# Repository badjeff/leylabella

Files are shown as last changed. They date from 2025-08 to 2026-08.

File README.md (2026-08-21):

# leylabella



### design principles
- symmetrical computer mouse
- all gripping surface covering with unique curvy descent, generate unique touch memory of gripping, amplify awaring of grip slip to reduce grip adjustment duration
- narrowing frontend bottom, increase pinky side friction, enhance lift and pitch control for flick movement
- 8 customisable buttons
- not-too-bad middle click
- able to trigger side button by squeezing the stams of thumb or ring finger, ensure fingertip does not need to slip around
- no visible screws
- adjustable surface sensor position. with PAW3395 breakout pcb. https://github.com/badjeff/paw3395-pcb
- mini finger trackball. with PMW3610 breakout pcb. https://github.com/badjeff/pmw3610-pcb
- mechnical trackball tightness control
- powered by [ZMK](https://github.com/zmkfirmware/zmk) => OSS, on-devie profiling, say no to (logxtxxh|razxx) eco-system
- magnetic hotswap palm rest (optimized for all grip style)
- medium size (claw grip @ 112mm x 61mm x 38mm; palm grip @ 117mm x 61mm x 38mm)
- rigid. (Zero crackly sound)
- stupidly easy facelifting. (see CAD file, open soruced, playback the timeline)
- ligthweight. (Errr, under 80g, made by PLA body with two sensors)
- fair battery life
- silent tactile switches
- conventional scroll wheel option

### gallery

<p float="left">
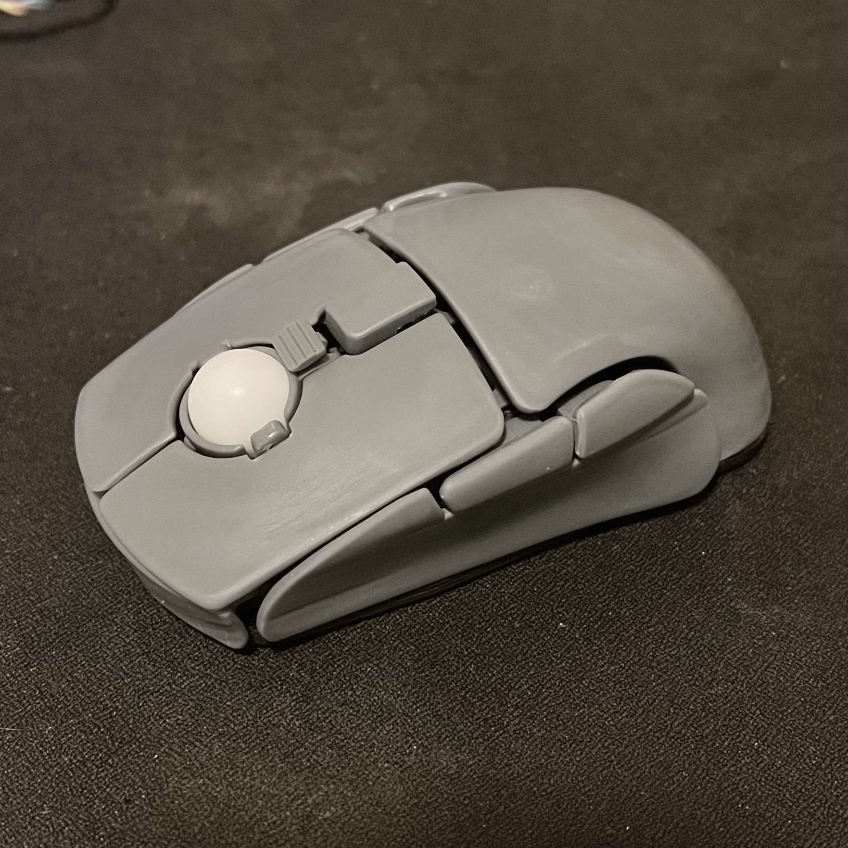
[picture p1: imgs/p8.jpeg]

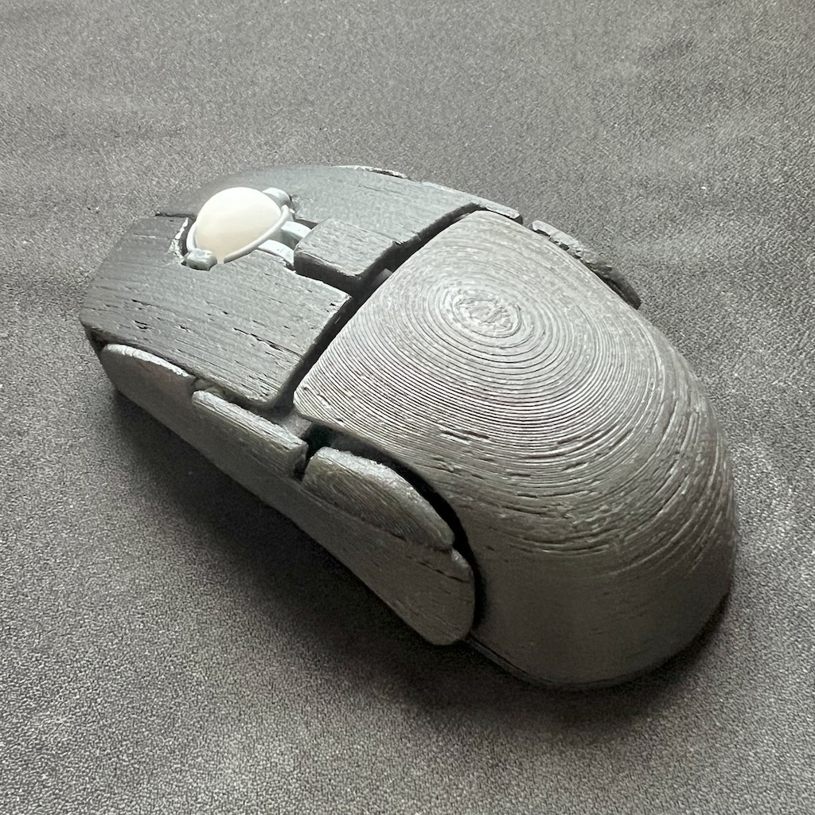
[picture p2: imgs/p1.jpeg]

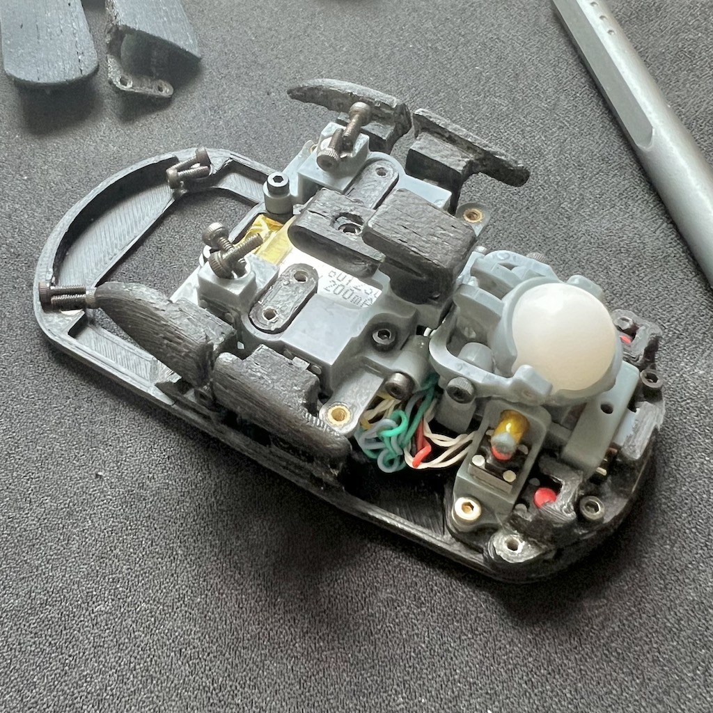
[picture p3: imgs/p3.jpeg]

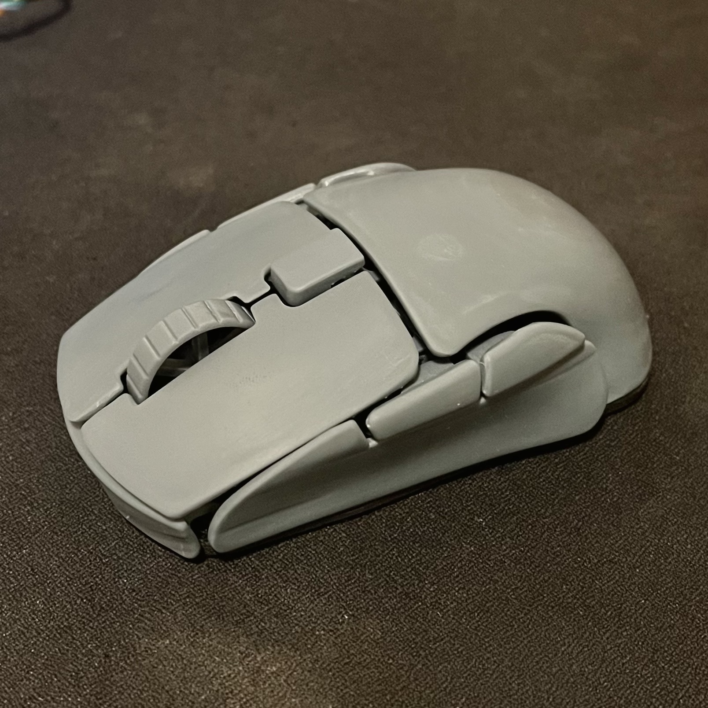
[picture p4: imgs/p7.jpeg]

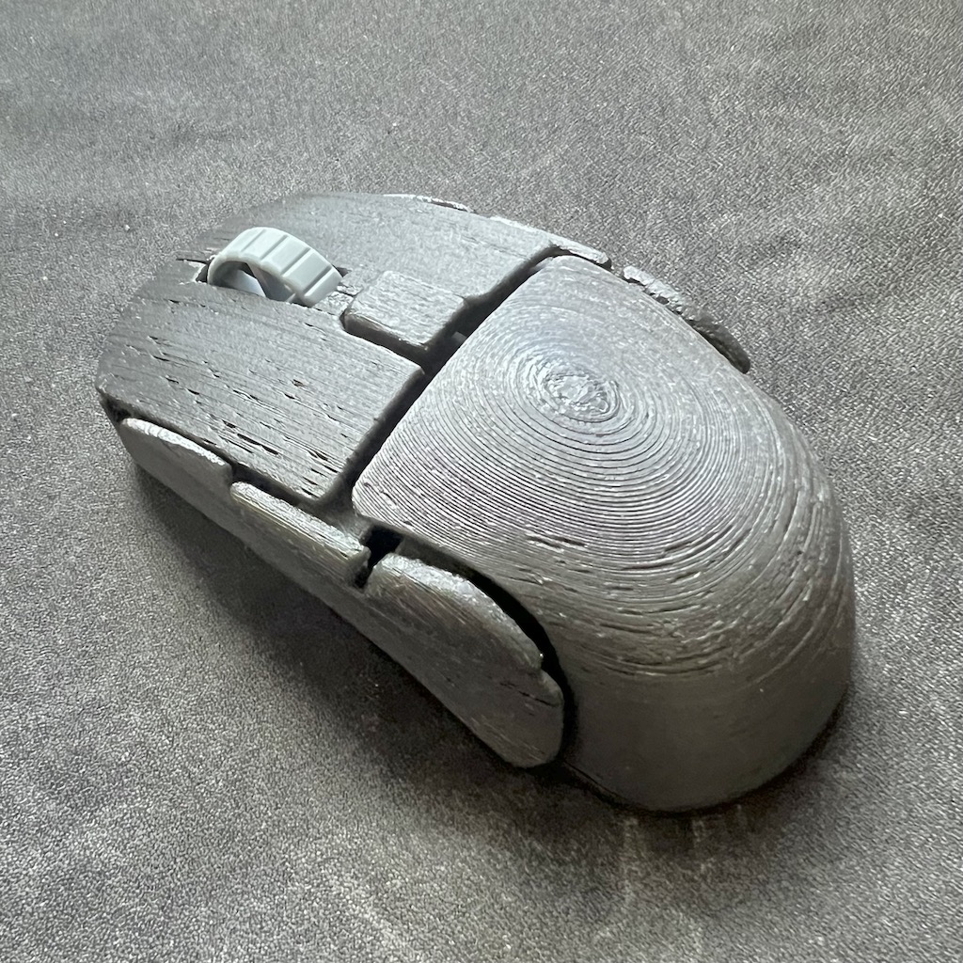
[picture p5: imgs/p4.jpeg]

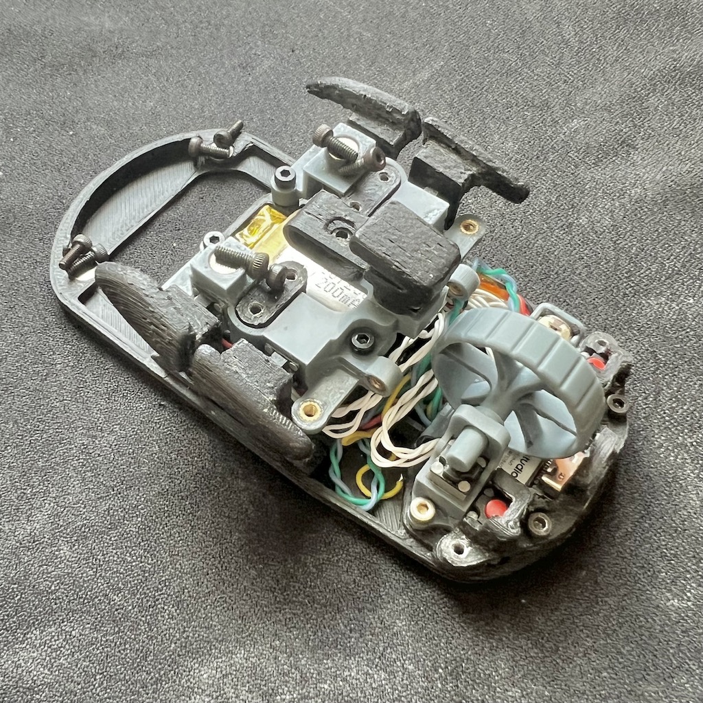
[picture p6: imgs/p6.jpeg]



</p>

<p float="left">
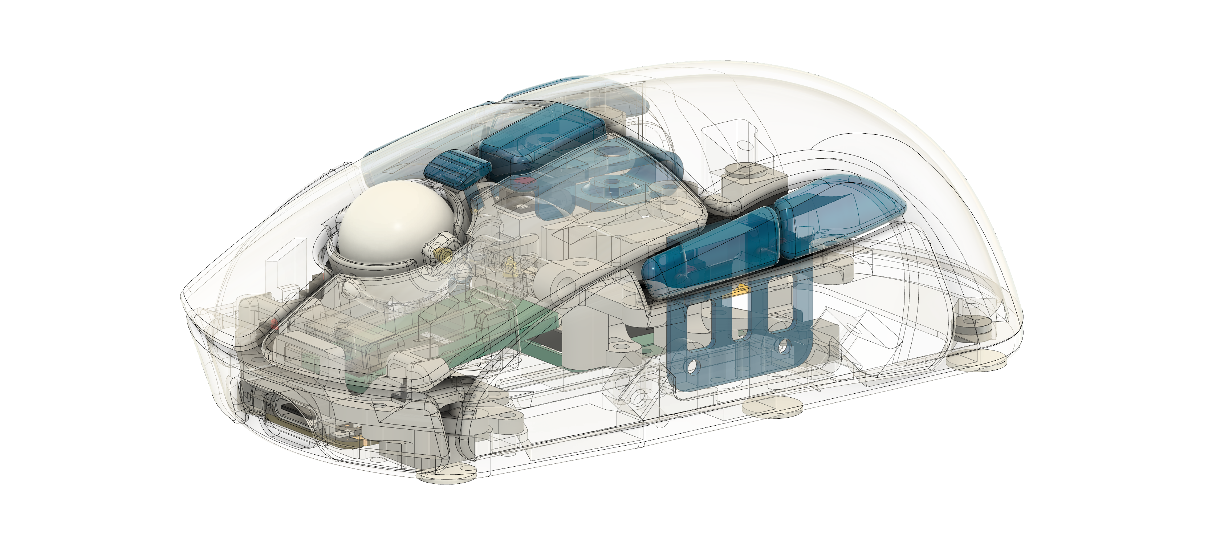
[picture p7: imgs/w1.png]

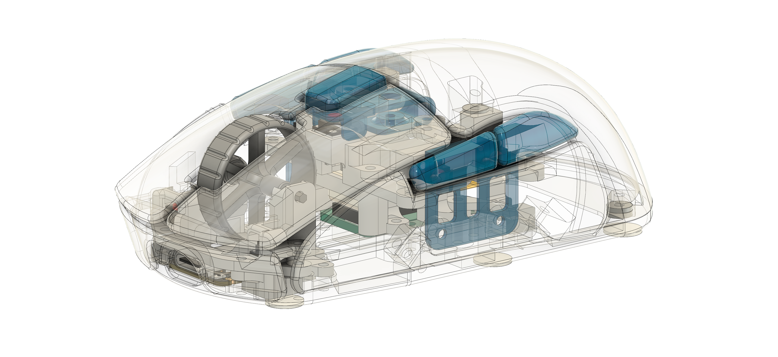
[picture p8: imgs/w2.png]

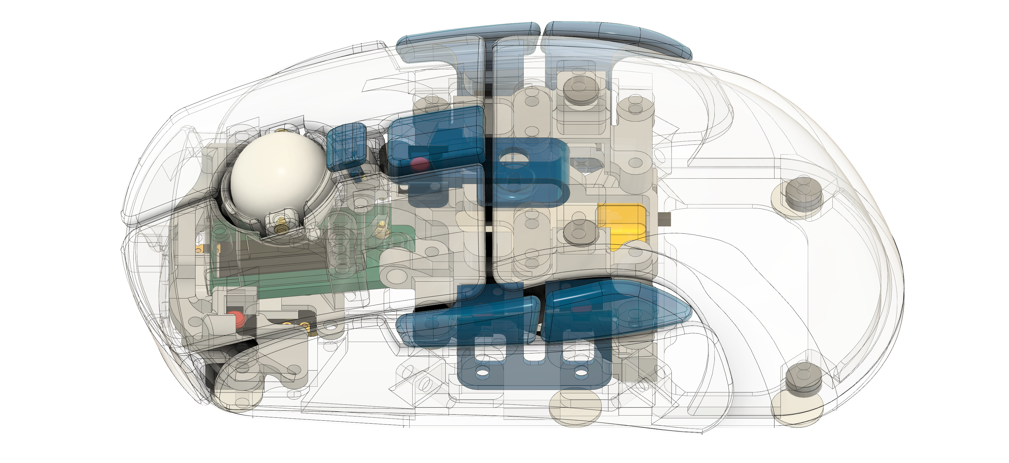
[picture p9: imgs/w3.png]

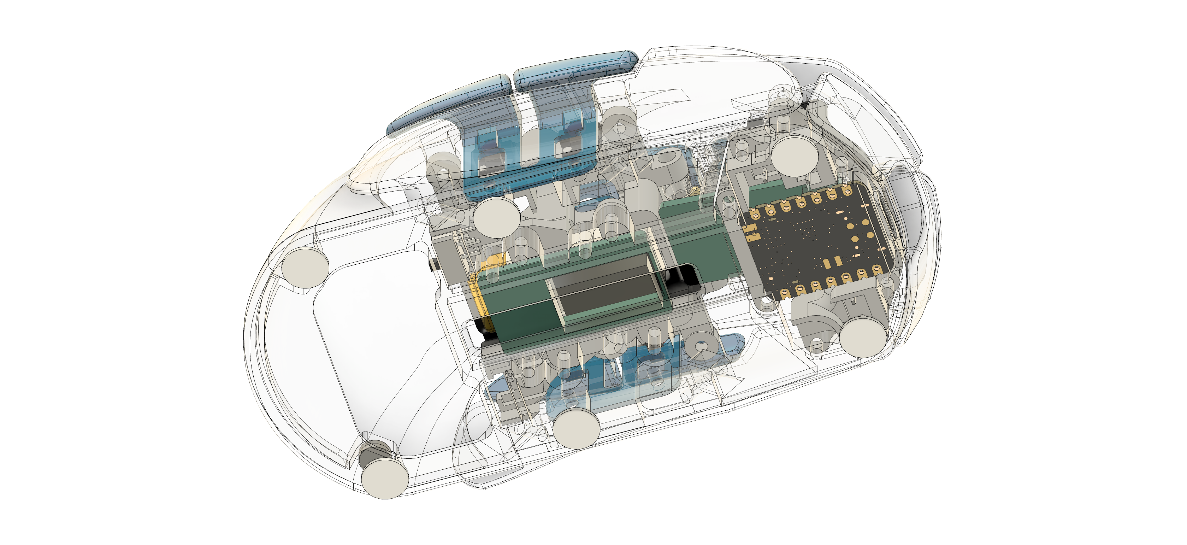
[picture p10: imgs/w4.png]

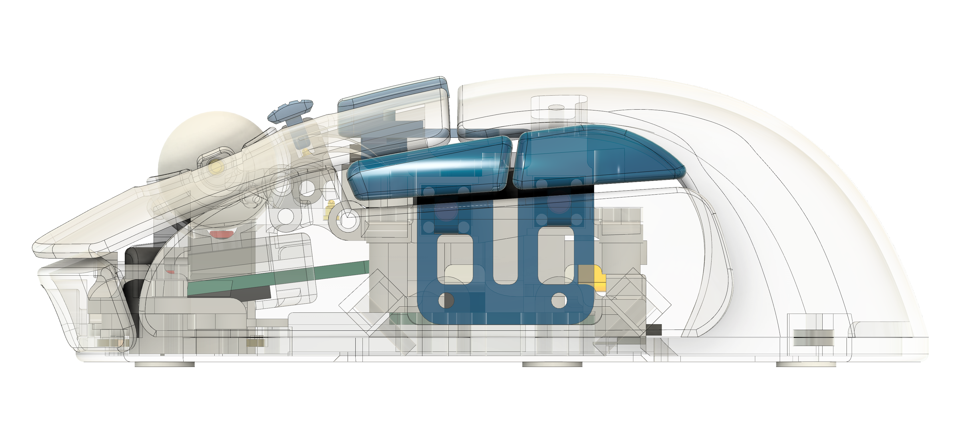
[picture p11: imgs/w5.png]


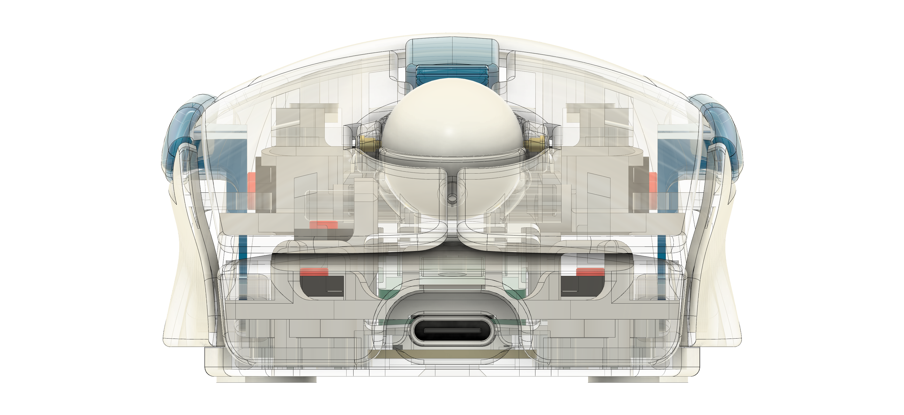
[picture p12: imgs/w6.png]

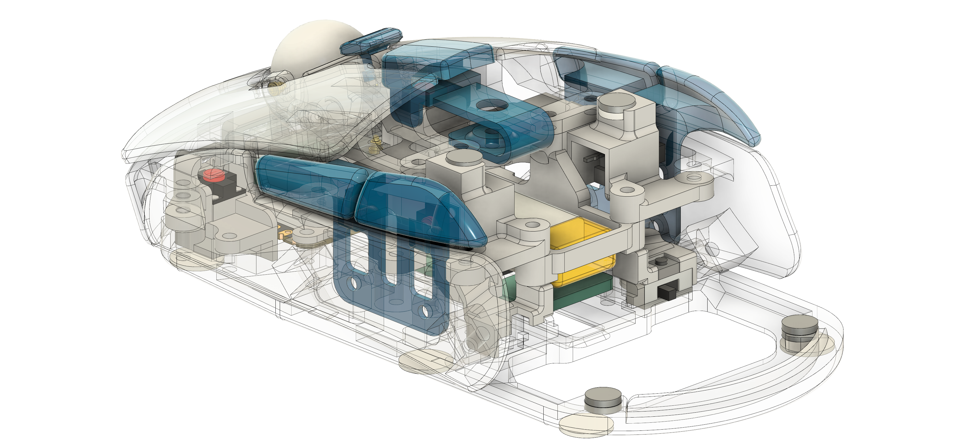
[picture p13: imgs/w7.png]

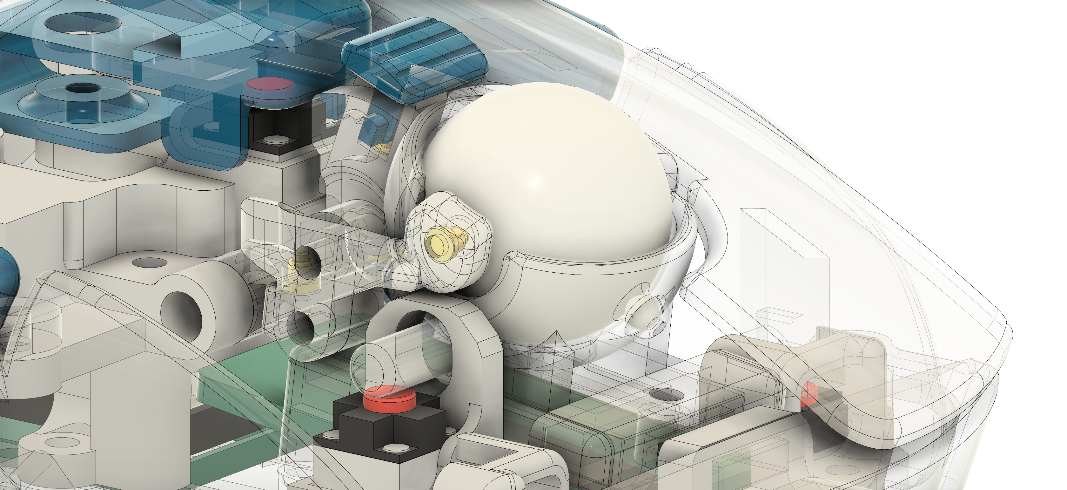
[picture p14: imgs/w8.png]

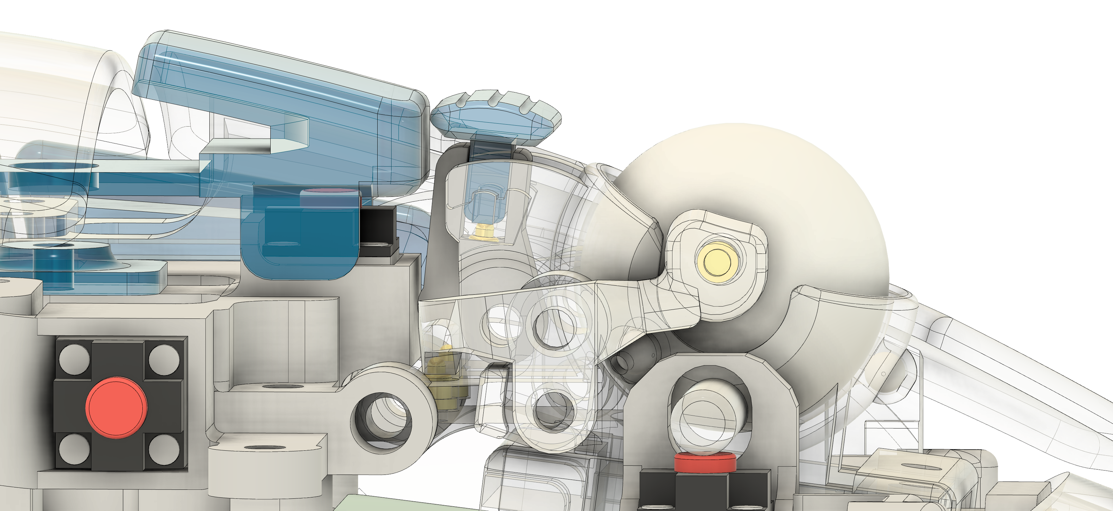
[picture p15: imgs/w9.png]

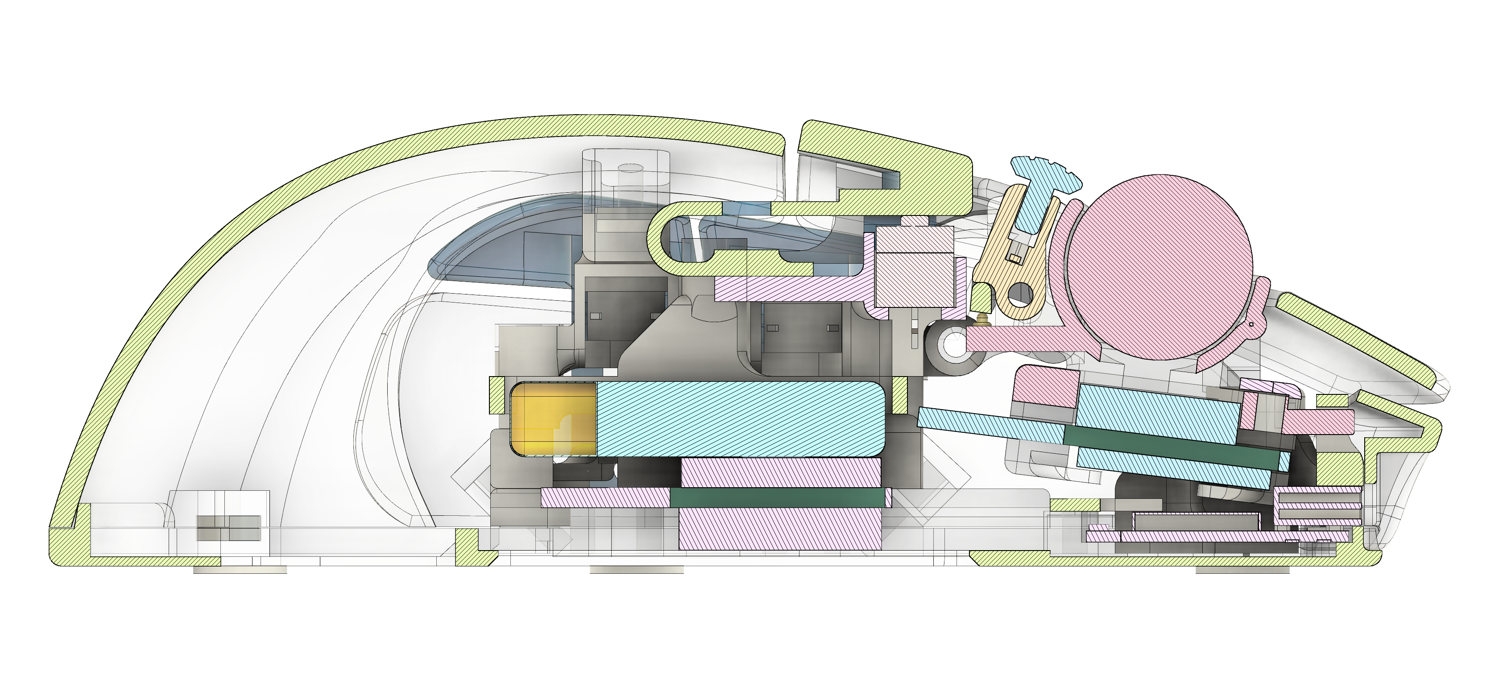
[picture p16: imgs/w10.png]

</p>

https://github.com/user-attachments/assets/b8692ff0-01a4-4cb0-a1dc-d5b0ee7fba73

### bom
|unit|item|
|-|-|
|1|Seeed Studio XIAO BLE (nRF52840)|
|1|PAW3395 Sensor with LOAE-LSI1 Lens [Breakout Board](https://github.com/badjeff/paw3395-pcb)|
|1|PWM3610 Sensor with LM18-LSI Lens [Breakout Board](https://github.com/badjeff/pmw3610-pcb)|
|8|Kailh CMI627301D07 6x6x7.3mm Silent Micro Switch|
|8|1N4148W T4 SOD-123 Diode|
|1|15mm Diameter Delrin POM Ball|
|5*|Pogo pin (2mm diameter x 2.5mm height)|
|3*|2mm static ceramic bearings (embedded in trackball socket)|
|1*|ALPS EC05-E1220401 (Vertical) Rotary Encoder|
|1|MSK-1153 6 Pins Power Switch|
|1|3x4x2mm Tact Switch Turtle Switch|
|1|M2 Screw Boxset (3-10mm)|
|4**|M2 Spacer 4mm diameter|
|4**|M2 Silicon O-ring|
|8|Neodymium Disc Magnets 5x1mm (Diameter x Tall)|
|1|601230 Lipo Battery (plus connector)|
|6|Thick Mouse Feet Skates Dots (~0.7mm)|
|1|30/28/26 AWG silicone wire|
|***|M2 Heat set inserts. ideal size: 3mm diameter x 3mm height.|

*: pogo pin and static ceramic bearings for trackball variant only. rotary encoder for scroll wheel variant only.

**: to implement PAW3395 sensor position adjustable from bottom of the body after assemble, o-rings and spacers are used to secure sensor breakout pcb on chassis.

***: need few heat set inserts if parts are going to be resin printed. all screw holes would fit m2 screws by design, requires to un-supressed feature in fusion360 CAD file to enlarge some m2 screw holes and count how many insert is needed.

### building guide / tips

- NOT for beginner. Requiring experience of building at least one wireless keyboard on [ZMK](https://github.com/zmkfirmware/zmk).
- print chassis plate with PLA, easier to screw
- print trackball socket with resin printing
- lens-to-surface distance ~2.4mm (+/-0.2mm). Assuming all mouse feet is ~0.65mm tall.
- both optical sensor breakout pcb (and its lens) has the same width and height, that both can fit in the sensor rail. Therefor, surface facing sensor would be swapped to PMW3610 (yeah, dual 3610 build) if +0.5mm to all mouse feet regarding different lens focus distance.

### firmware

the ZMK firmware config repository can be find at [badjeff/leylabella-zmk-config](https://github.com/badjeff/leylabella-zmk-config).

## license

available under the [CERN-OHL-P v2](/LICENSE) permissive license.

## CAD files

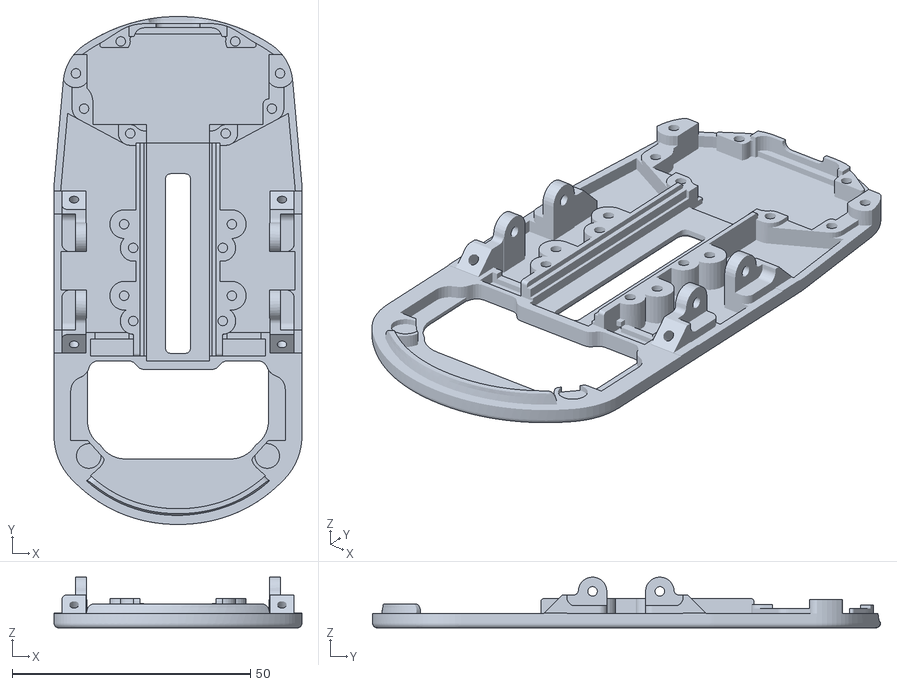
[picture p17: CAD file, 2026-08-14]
STLs/1 - base.stl
52.0 x 106.5 x 10.7

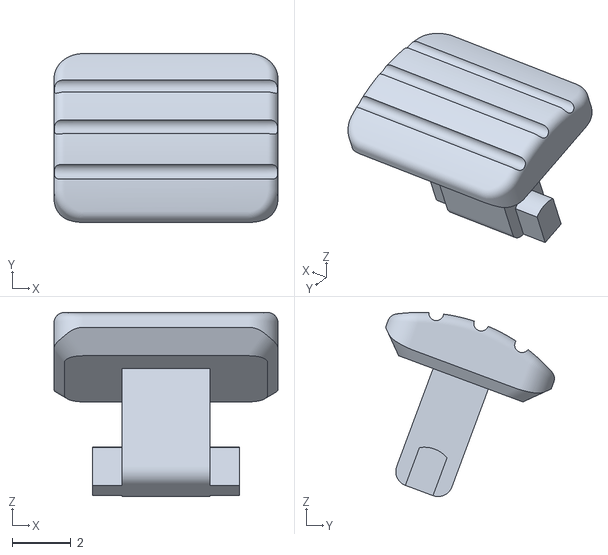
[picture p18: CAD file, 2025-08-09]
STLs/7a - trackball/tball latch sw.stl
7.60 x 5.73 x 6.25

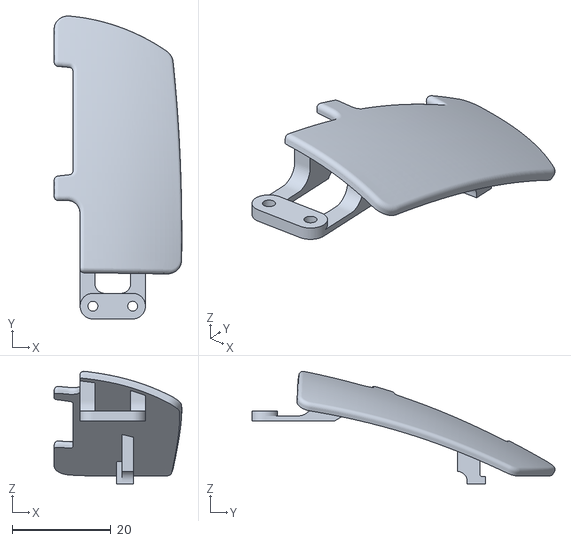
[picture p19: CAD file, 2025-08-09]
STLs/7b - scrollwheel/RMB.stl
25.9 x 61.4 x 22.8

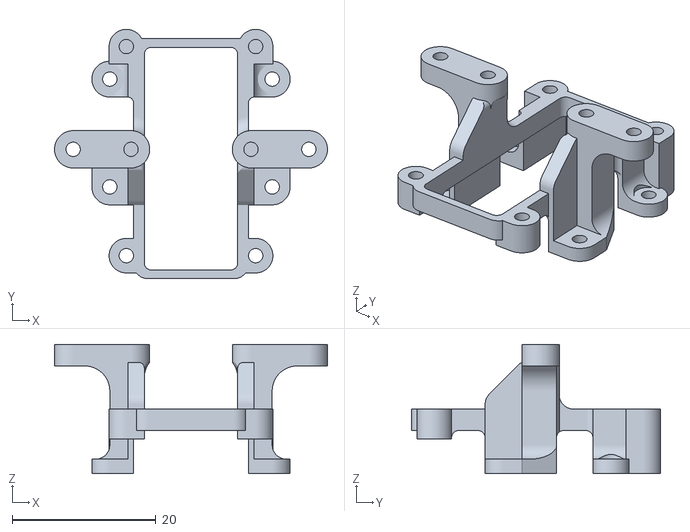
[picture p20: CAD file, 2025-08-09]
STLs/2 - mid tower.stl
38.0 x 34.7 x 18.0

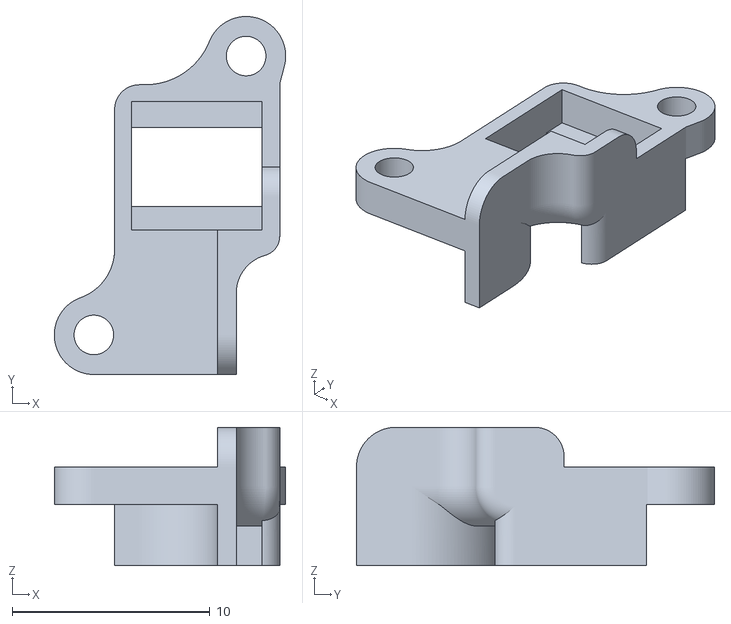
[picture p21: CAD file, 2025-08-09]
STLs/7a - trackball/L btn mount.stl
11.7 x 18.1 x 7.00

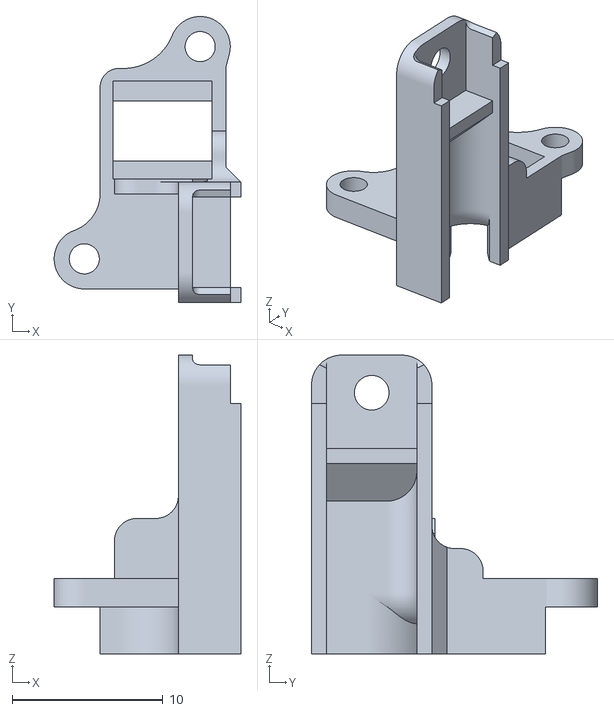
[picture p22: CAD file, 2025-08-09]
STLs/7b - scrollwheel/L btn mount.stl
12.4 x 19.0 x 19.9

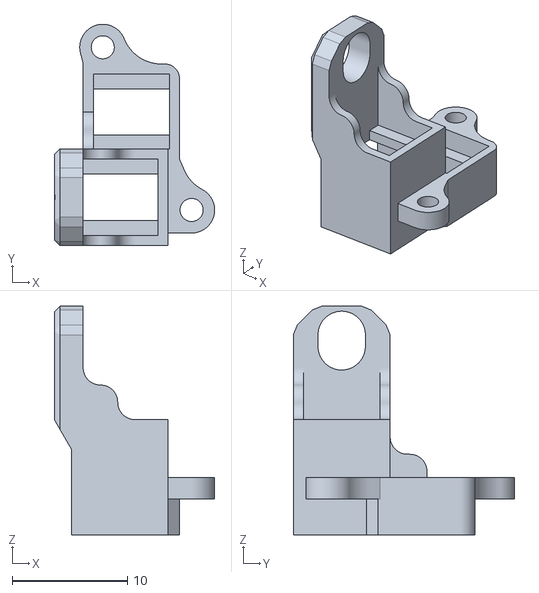
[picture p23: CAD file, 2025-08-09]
STLs/6 - R btn mount.stl
13.9 x 19.2 x 19.9

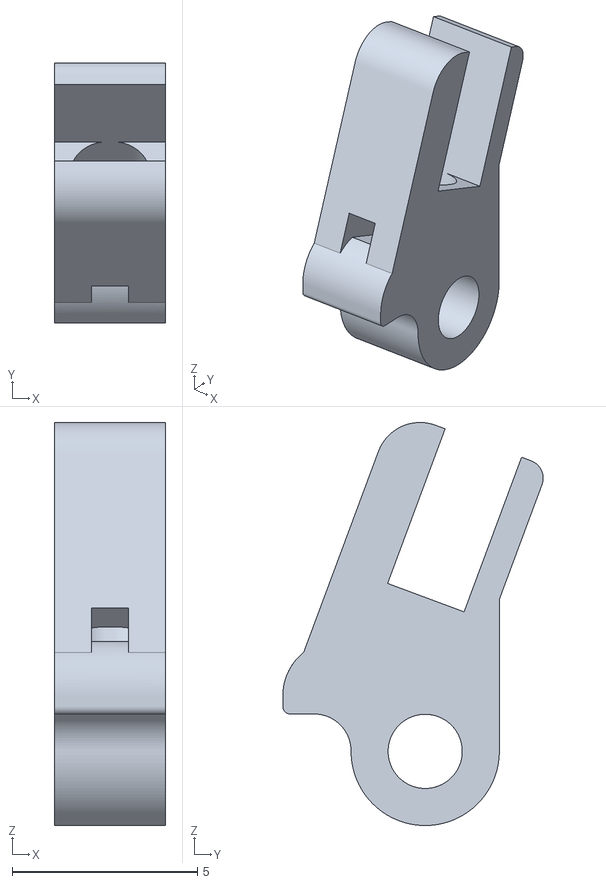
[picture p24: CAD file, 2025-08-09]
STLs/7a - trackball/tball latch tube.stl
3.00 x 7.02 x 10.9

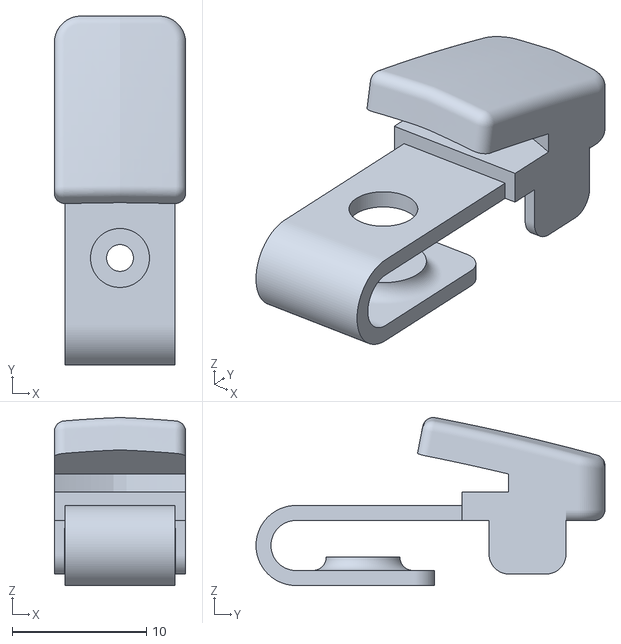
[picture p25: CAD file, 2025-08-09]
STLs/14 - shd btn.stl
9.80 x 26.0 x 12.5

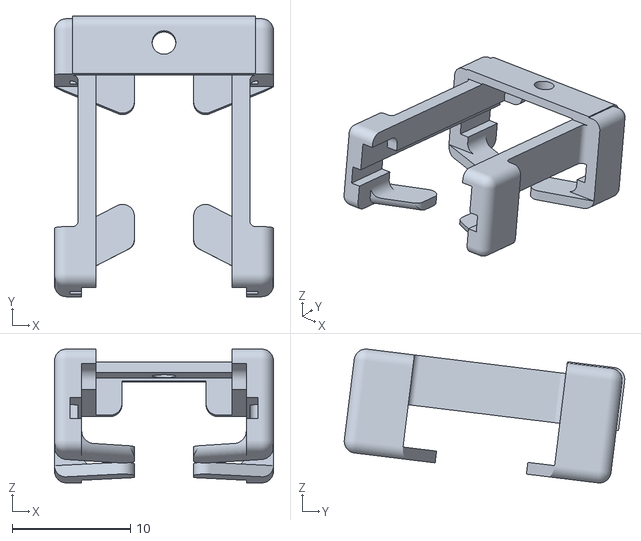
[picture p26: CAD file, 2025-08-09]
STLs/7a - trackball/tball sensor clip.stl
18.5 x 23.7 x 11.3

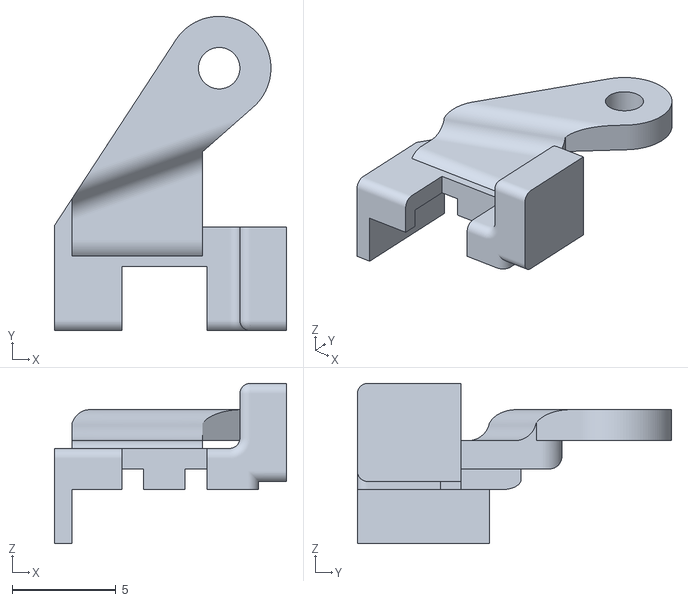
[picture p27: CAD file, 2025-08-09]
STLs/4b - pwr cover left.stl
11.2 x 15.2 x 7.74

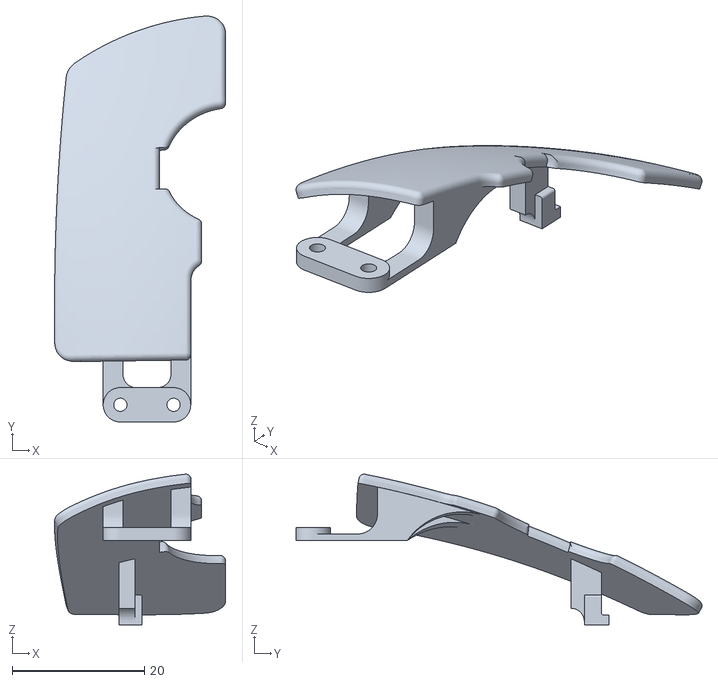
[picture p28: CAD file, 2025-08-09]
STLs/7a - trackball/LMB.stl
25.9 x 61.4 x 22.8

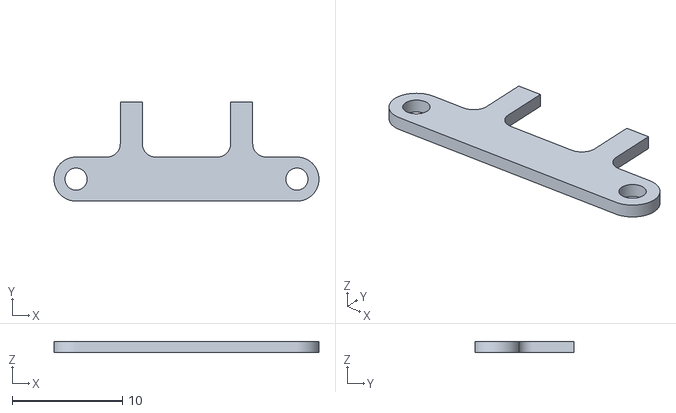
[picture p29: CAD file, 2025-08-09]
STLs/5 - mcu holder.stl
24.0 x 9.00 x 1.00

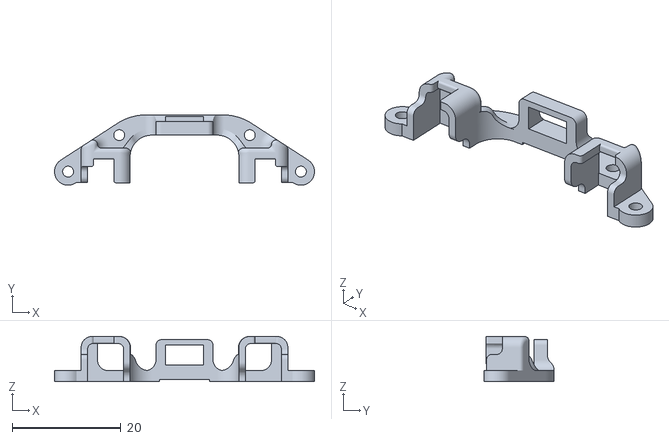
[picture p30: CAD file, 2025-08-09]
STLs/8 - guider.stl
47.8 x 12.9 x 8.29

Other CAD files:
STLs/7b - scrollwheel/LMB.stl
STLs/7a - trackball/RMB.stl
STLs/3 - ribs.stl
STLs/4a - pwr cover right.stl

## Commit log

2025-08-09 init commit
    [14 - shd btn.stl, 2 - mid tower.stl, 3 - ribs.stl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]
2026-08-14 adjust lens surface distance to maximise SQUAL value
    [1 - base.stl]
2026-08-20 remove obsolete STL file and update path for base model
    [1 - base.stl]
2026-08-21 fix: update lens-to-surface distance specification for improved accuracy
